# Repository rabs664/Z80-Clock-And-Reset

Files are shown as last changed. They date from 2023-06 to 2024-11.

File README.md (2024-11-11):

# Z80-Clock-And-Reset
Simple 555 based astable and monostable clock and reset board.

clock and reset v1 2

The Z80 Clock and Reset board provides a variable astable clock where the frequency can be controlled by R8 or a monostable clock to allow the clock to be "single-stepped". The switch S1 toggles between the astable and monostable clock. Additional the switch S3 provides a reset signal for use with the Z80. 

Astable Clock Output

Z80-Astable-Clock-Image

## Objective
Support Z80 CPU learning, specifically used with associated Z80 CPU Boards.

## Background
Used extensively during early Z80 learning to single step the clock or slow run the clock and watch the Z80 activity.

## Testing
The Z80 Clock and Reset V1.2 board has been built and tested. 

## PCBs
Gerber files are available in Code.

## Components
This [Digi-Key List](https://www.digikey.co.uk/en/mylists/list/MAI0B51H04) contains all components.

## Resources
[Zed80 Website](http://zed80.com/Z80-RETRO/index_Home.html)

[Ben Eater Clock](https://eater.net/8bit/clock)

## Acknowledgements
Don Prefontaine 

Peter Murray

[Ben Eater](https://eater.net)

# Release History
## Version 1.2
* First Release

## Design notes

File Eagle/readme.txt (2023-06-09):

This folder contains the Eagle Schematic, Board and Gerber output files.

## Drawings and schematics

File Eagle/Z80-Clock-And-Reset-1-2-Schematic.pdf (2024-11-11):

# NE555 VCC GND

# 0.01uF TL2285EE

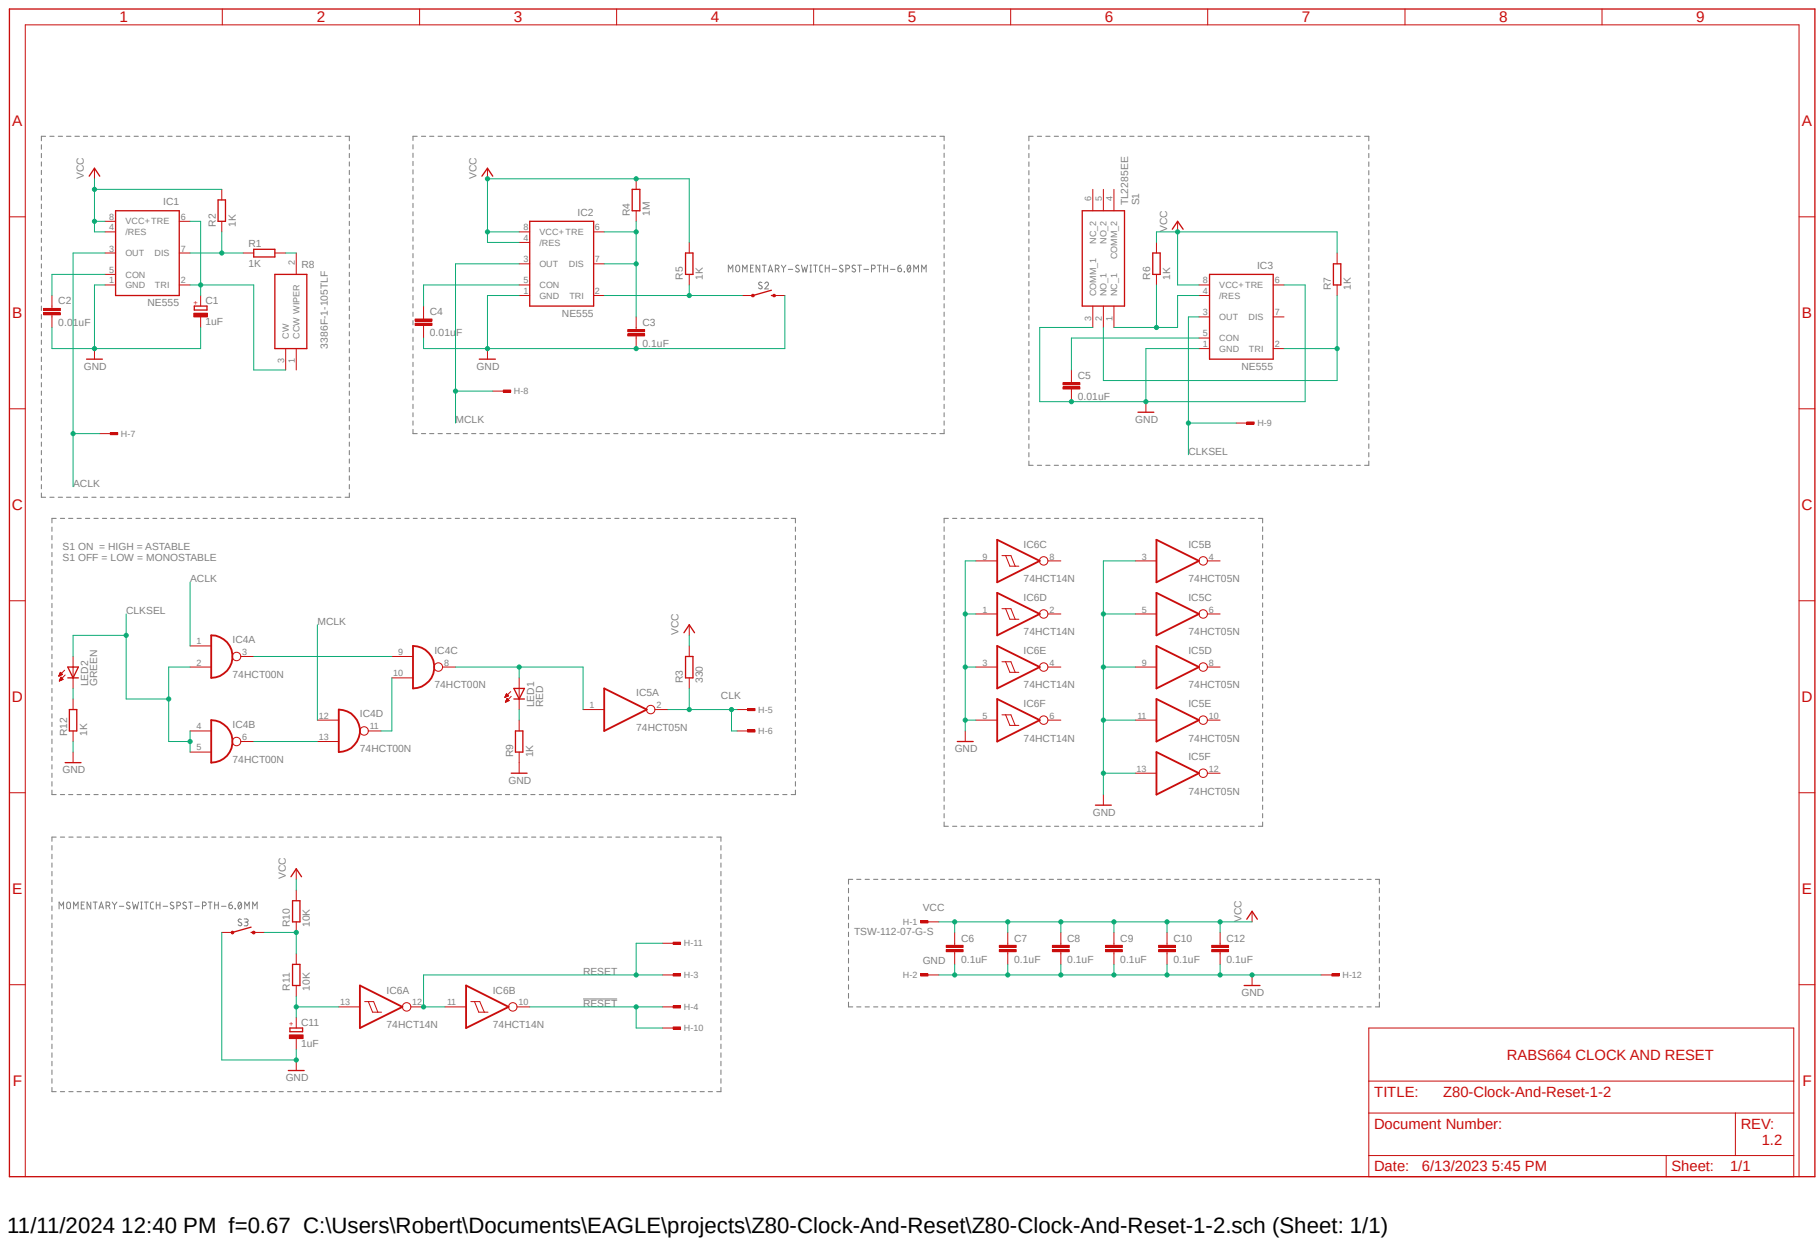
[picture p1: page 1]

Document Number: | REV: 1.2

Date: 6/13/2023 5:45 PM | Sheet: 1/1

11/11/2024 12:40 PM f=0.67 C:\Users\Robert\Documents\EAGLE\projects\Z80-Clock-And-Reset\Z80-Clock-And-Reset-1-2.sch (Sheet: 1/1)

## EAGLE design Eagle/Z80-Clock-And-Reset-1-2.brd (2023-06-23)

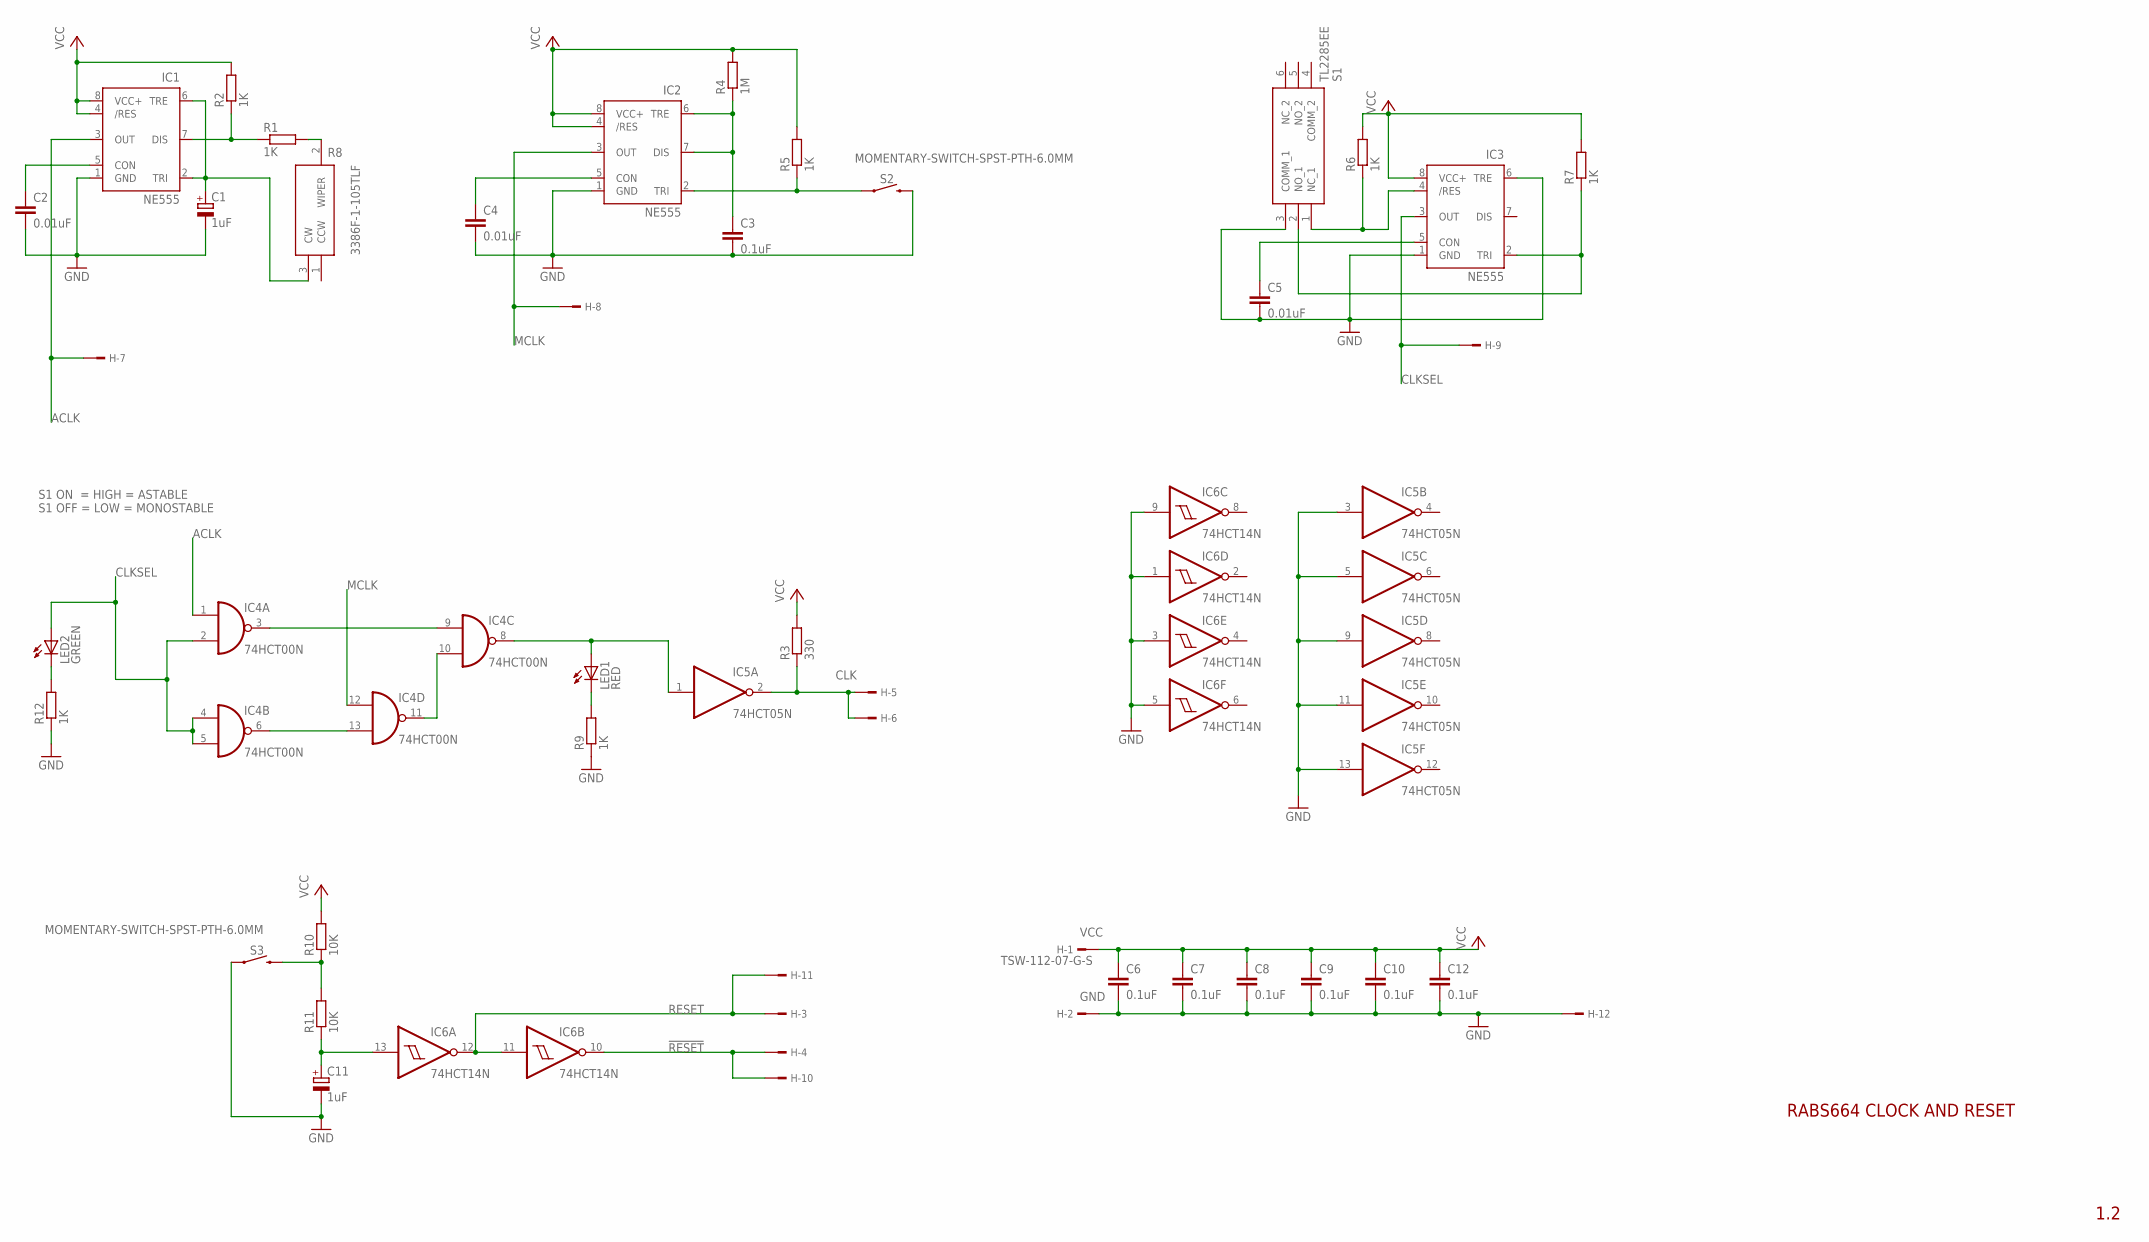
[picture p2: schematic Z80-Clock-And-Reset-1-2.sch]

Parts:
C1, C11: 1uF; E2,5-6E
C2, C4, C5: 0.01uF; C050-025X075
C3, C6, C7, C8, C9, C10, C12: 0.1uF; C050-025X075
H: TSW-112-07-G-S; TSW-112-XX-G-S
IC1, IC2, IC3: NE555; DIL-08
IC4: 74HCT00N; DIL14
IC5: 74HCT05N; DIL14
IC6: 74HCT14N; DIL14
LED1: RED; LED3MM
LED2: GREEN; LED3MM
R1, R2, R5, R6, R7, R9, R12: 1K; 0207/10
R3: 330; 0207/10
R4: 1M; 0207/10
R8: 3386F-1-103TLF; 3386F1103TLF
R10, R11: 10K; 0207/10
S1: TL2285EE
S2, S3: MOMENTARY-SWITCH-SPST-PTH-6.0MM; TACTILE_SWITCH_PTH_6.0MM

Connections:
!RESET: H.4, H.10, IC6.10 (O)
ACLK: H.7, IC1.3 (OUT), IC4.1 (I0)
CLK: H.5, H.6, IC5.2 (O), R3.1
CLKSEL: H.9, IC3.3 (OUT), IC4.2 (I1), IC4.4 (I0), IC4.5 (I1), LED2.A
GND: C1.-, C2.2, C3.2, C4.2, C5.2, C6.2, C7.2, C8.2, C9.2, C10.2, C11.-, C12.2, H.2, H.12, IC1.1 (GND), IC2.1 (GND), IC3.1 (GND), IC3.6 (TRE), IC4.7 (GND), IC5.3 (I), IC5.5 (I), IC5.7 (GND), IC5.9 (I), IC5.11 (I), IC5.13 (I), IC6.1 (I), IC6.3 (I), IC6.5 (I), IC6.7 (GND), IC6.9 (I), R9.1, R12.1, S1.3 (COMM_1), S2.3 (2), S3.1
MCLK: H.8, IC2.3 (OUT), IC4.12 (I0)
unnamed: C2.1, IC1.5 (CON)
unnamed: C1.+, IC1.2 (TRI), IC1.6 (TRE), R8.3 (CW)
unnamed: IC1.7 (DIS), R1.1, R2.1
unnamed: IC3.4 (/RES), R6.1, S1.1 (NC_1)
unnamed: R1.2, R8.2 (WIPER)
unnamed: C3.1, IC2.6 (TRE), IC2.7 (DIS), R4.1
unnamed: C4.1, IC2.5 (CON)
unnamed: IC2.2 (TRI), R5.1, S2.1
unnamed: LED2.K (C), R12.2
unnamed: IC4.3 (O), IC4.9 (I0)
unnamed: C5.1, IC3.5 (CON)
unnamed: IC4.6 (O), IC4.13 (I1)
unnamed: IC3.2 (TRI), R7.1, S1.2 (NO_1)
unnamed: IC4.10 (I1), IC4.11 (O)
unnamed: IC4.8 (O), IC5.1 (I), LED1.A
unnamed: LED1.K (C), R9.2
unnamed: R10.1, R11.2, S3.3 (2)
unnamed: C11.+, IC6.13 (I), R11.1
RESET: H.3, H.11, IC6.11 (I), IC6.12 (O)
VCC: C6.1, C7.1, C8.1, C9.1, C10.1, C12.1, H.1, IC1.4 (/RES), IC1.8 (VCC+), IC2.4 (/RES), IC2.8 (VCC+), IC3.8 (VCC+), IC4.14 (VCC), IC5.14 (VCC), IC6.14 (VCC), R2.2, R3.2, R4.2, R5.2, R6.2, R7.2, R10.2

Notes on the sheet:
RABS664 CLOCK AND RESET
1.2
3386F-1-105TLF
S1 ON = HIGH = ASTABLE S1 OFF = LOW = MONOSTABLE

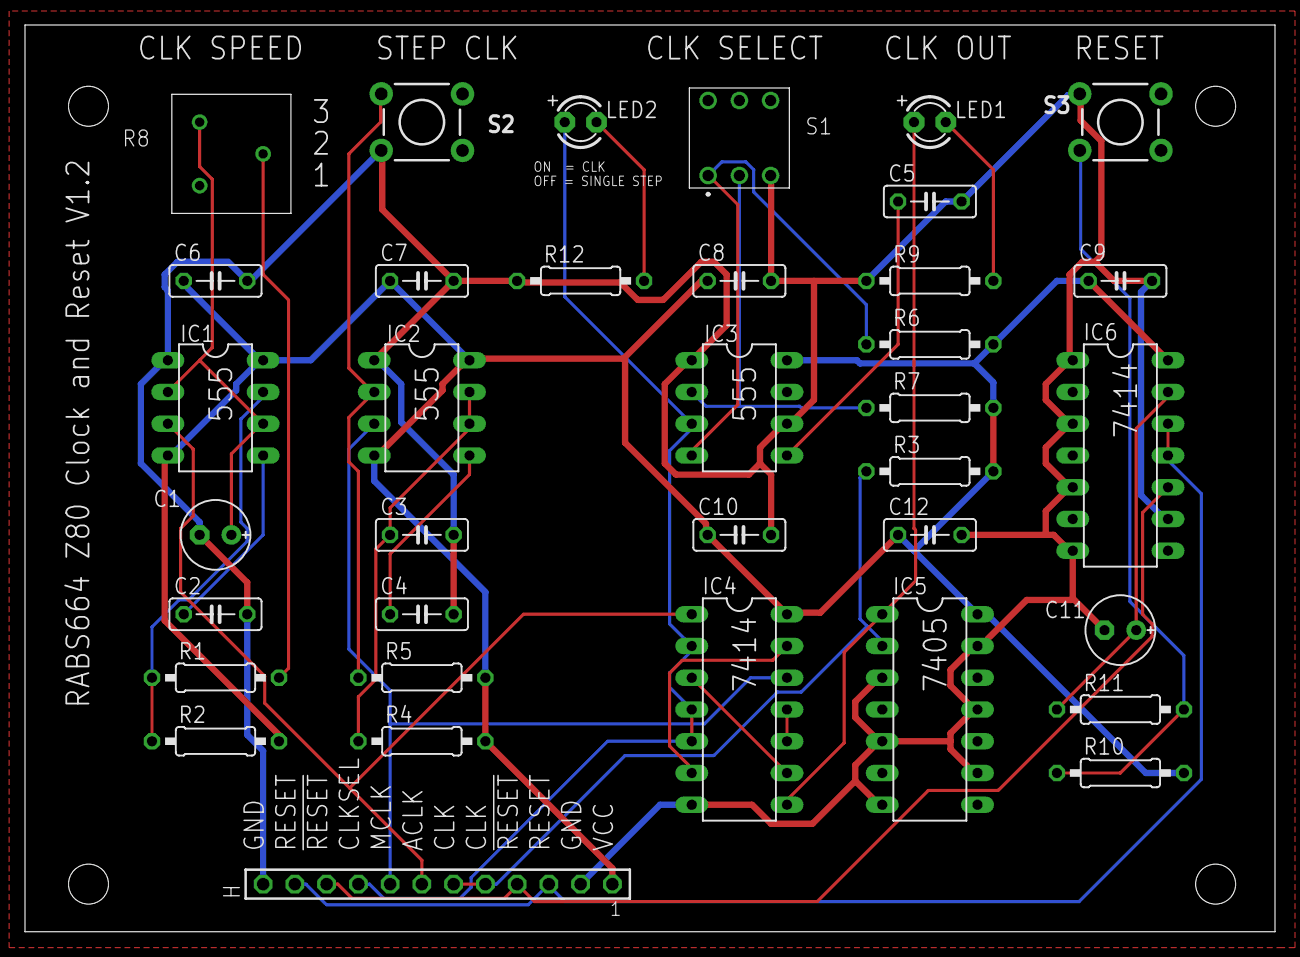
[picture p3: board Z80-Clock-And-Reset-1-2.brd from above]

Board: 2 copper layers, 100.0 x 72.5 mm, 36 parts (0 on the bottom side), 26 nets.

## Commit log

2023-06-13 Create BOM
2024-11-11 Update README.md
    Update PIC of board to version 1.2 and remove references to private projects.
2024-11-11 Add PDF of schematic

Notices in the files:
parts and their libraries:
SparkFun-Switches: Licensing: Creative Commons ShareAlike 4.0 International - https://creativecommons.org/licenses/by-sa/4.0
